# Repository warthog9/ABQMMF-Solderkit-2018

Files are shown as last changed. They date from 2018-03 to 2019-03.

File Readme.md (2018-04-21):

# 2018 Albuquerque Mini-Maker Faire Soldering Kit

This is the 2018 Albuquerque Mini-Maker Faire soldering kit, it's intended
to be a useful item that people will actually use as opposed to just a
series of blinky LEDs.  It makes use of the NodeMCU, which is based on the
ESP8266, a microcontroller that has wifi capabilities.

## Out of the box
Out of the box the kit will include the following things:
* PCB of the Cloud Sun variety (pictured below)
* 2x 15-pin, female, 0.1" headers
* 2x 4-pin, female, 0.1" headers
* 1x 1K Ohm resistor
* 1x 5mm Red LED
* 1x Diode
* 1x 3-AAA battery pack
* 1x Red button (intended to go in the middle - but doesn't matter)
* 4x Black buttons (electrically identical to the red)
* 1x 2x10-pin, male, 0.1" header
* 1x I2C, 4-pin, OLED screen
* 1x BME280, I2C 4-pin, breakout board
* 1x NodeMCU v2 (CP2102 USB chip type)

The board will boot up, once soldered up, and will show the following information on the OLED screen:
* Battery level (upper right corner)
* Temperature
* Barometric pressure
* Relative humidity

The buttons do the following:
* Top: Increases OLED screen brightness
* Bottom: Decreases OLED screen brightness
* Middle: Toggles temperature readout between Celsius and Fahrenheit (Default Fahrenheit)
* Left: Toggles between condensed or extended text on the OLED screen
* Right: Will toggle the two extra LEDs on the ESP12e/f module and the NodeMCU itself

The NodeMCU has been pre-loaded with [MicroPython](https://micropython.org), which is a slimmed down version of Python 3 intended for micro-controllers.  This is greater for people to start with, and you can find some basic tutorials on how to interact with the board quickly here:

* https://docs.micropython.org/en/latest/esp8266/esp8266/tutorial/intro.html
* https://github.com/unreproducible/tinysnakes

Wifi is disabled for this demo via [boot.py](https://github.com/warthog9/ABQMMF-Solderkit-2018/blob/master/src/boot.py), but can be easily changed and/or re-enabled.

Files were uploaded to the board using [ampy](https://github.com/adafruit/ampy)

## Schematic

Full schematic is here: [Schematic PDF](abqmmf2018-schematic.pdf)

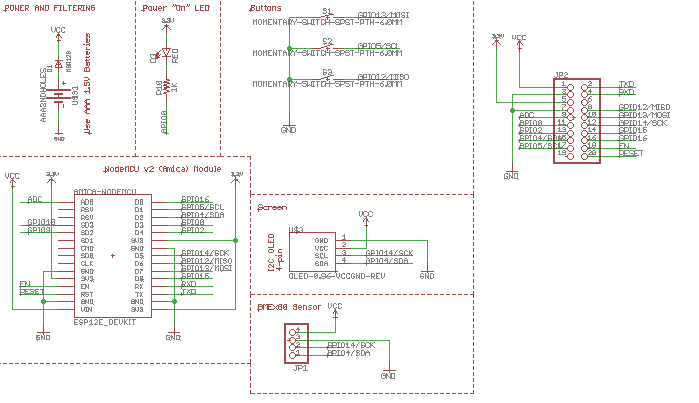
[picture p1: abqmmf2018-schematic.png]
Schematic image


### PCB outline
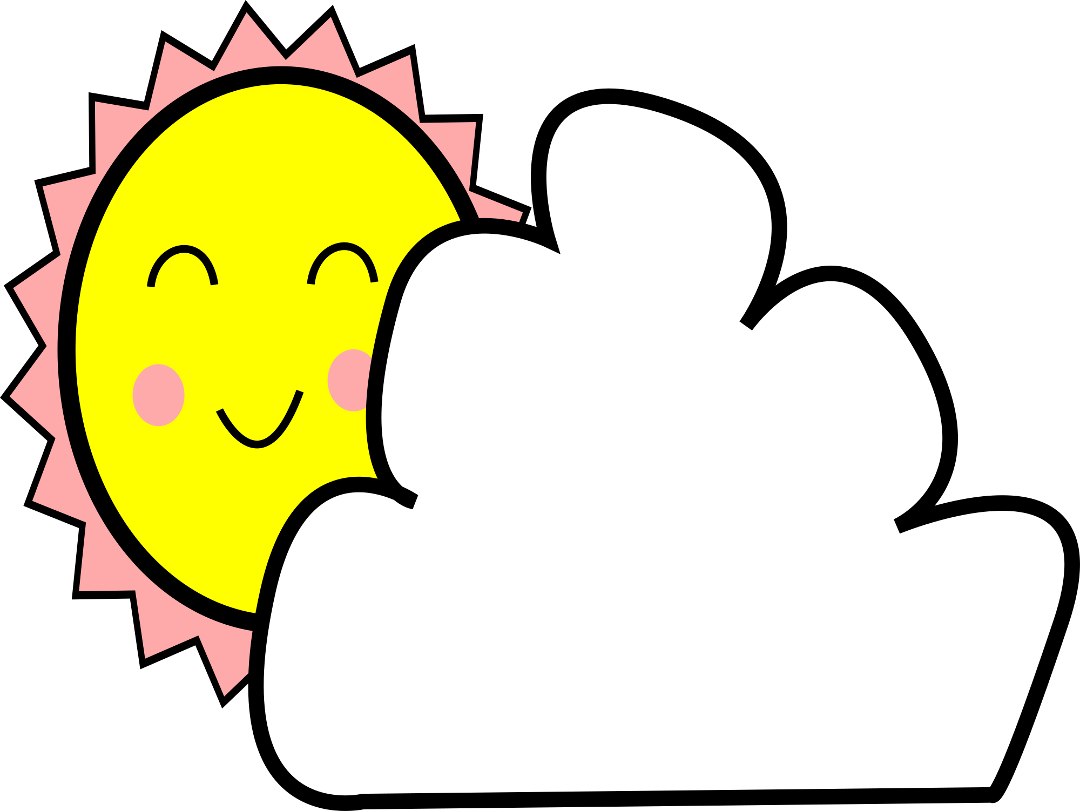
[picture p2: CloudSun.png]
Silkscreen and PCB Outline


### Prototype built up
Prototype board mostly built up

### Raw PCBs (prototypes)
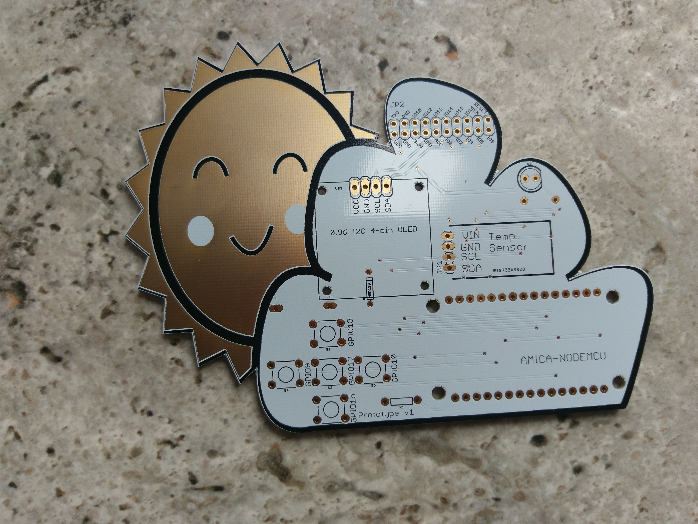
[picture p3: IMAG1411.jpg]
Bare prototype board - top

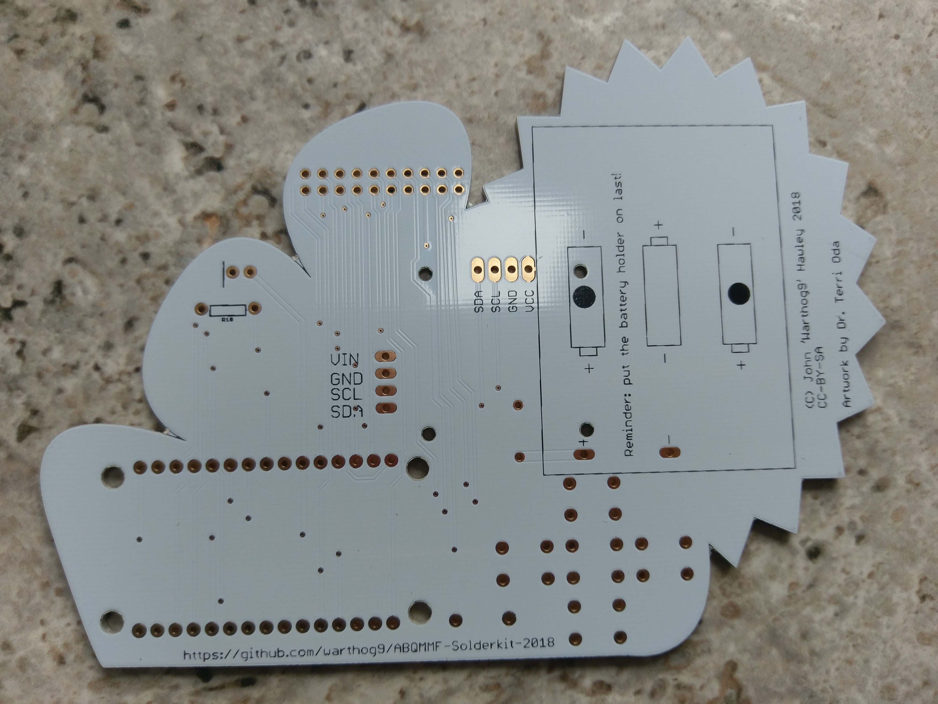
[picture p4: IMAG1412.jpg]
Bare prototype board - bottom


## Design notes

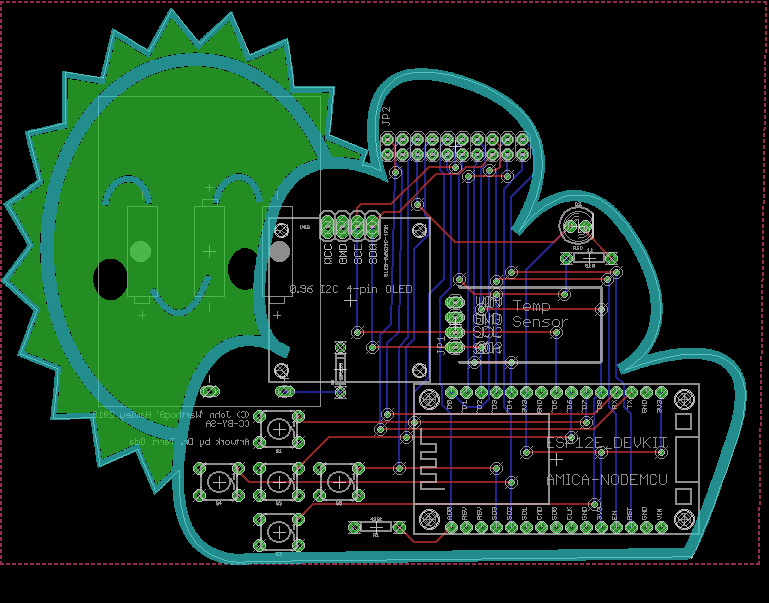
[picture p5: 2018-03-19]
CloudSun Board.png

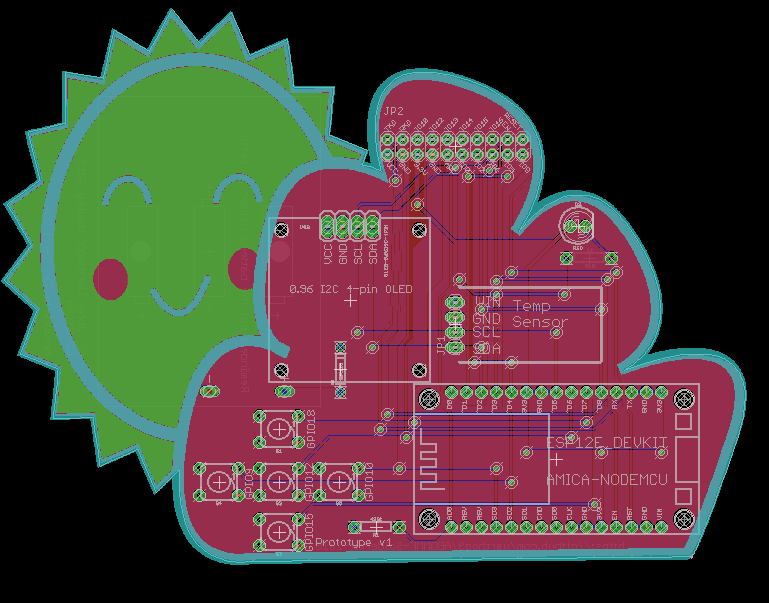
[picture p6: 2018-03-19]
CloudSun Board2.png

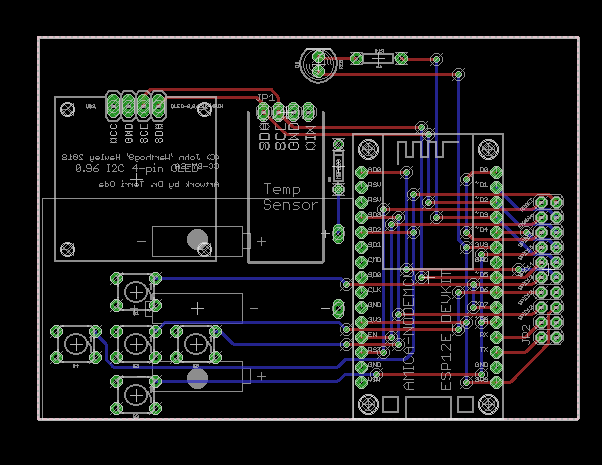
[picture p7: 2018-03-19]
board.png

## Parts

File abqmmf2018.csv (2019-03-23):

Part | Value | Device | Package | Description | PROD_ID | SF_SKU | VALUE
AMICA-NODEMCU | ESP12E_DEVKIT | ESP12E_DEVKIT | ESP12E_DEVKIT | ESP12E DEVKIT BOARD
D1 | MBR120 | DIODEDO-1N4148 | DO-1N4148 | Diode
D3 | RED | LED5MM | LED_5MM | LED (Generic)
JP1 |  | PINHD-1X4 | 1X04 | PIN HEADER
JP2 |  | PINHD-2X10 | 2X10 | PIN HEADER
R1 | 420k | 1KOHM-HORIZ-1/4W-1% | AXIAL-0.3 | 1kO resistor | RES-12182 |  | 1k
R10 | 1k | 1KOHM-HORIZ-1/4W-1% | AXIAL-0.3 | 1kO resistor | RES-12182 |  | 1k
S1 | MOMENTARY-SWITCH-SPST-PTH-6.0MM | MOMENTARY-SWITCH-SPST-PTH-6.0MM | TACTILE_SWITCH_PTH_6.0MM | Momentary Switch (Pushbutton) - SPST | SWCH-08441 | COM-00097
S2 | MOMENTARY-SWITCH-SPST-PTH-6.0MM | MOMENTARY-SWITCH-SPST-PTH-6.0MM | TACTILE_SWITCH_PTH_6.0MM | Momentary Switch (Pushbutton) - SPST | SWCH-08441 | COM-00097
S3 | MOMENTARY-SWITCH-SPST-PTH-6.0MM | MOMENTARY-SWITCH-SPST-PTH-6.0MM | TACTILE_SWITCH_PTH_6.0MM | Momentary Switch (Pushbutton) - SPST | SWCH-08441 | COM-00097
U$3 | OLED-0.96I2C-4PIN | OLED-0.96I2C-4PIN | OLED-I2C-4PIN | Common 0.96 OLED screen assembly
U$31 | AAA3NOHOLES | AAA3NOHOLES | AAA3-NOHOLES

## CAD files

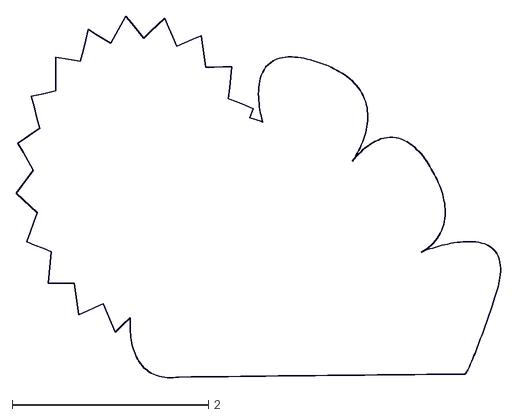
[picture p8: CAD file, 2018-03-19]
CloudSun-outline.dxf
4.94 x 3.69

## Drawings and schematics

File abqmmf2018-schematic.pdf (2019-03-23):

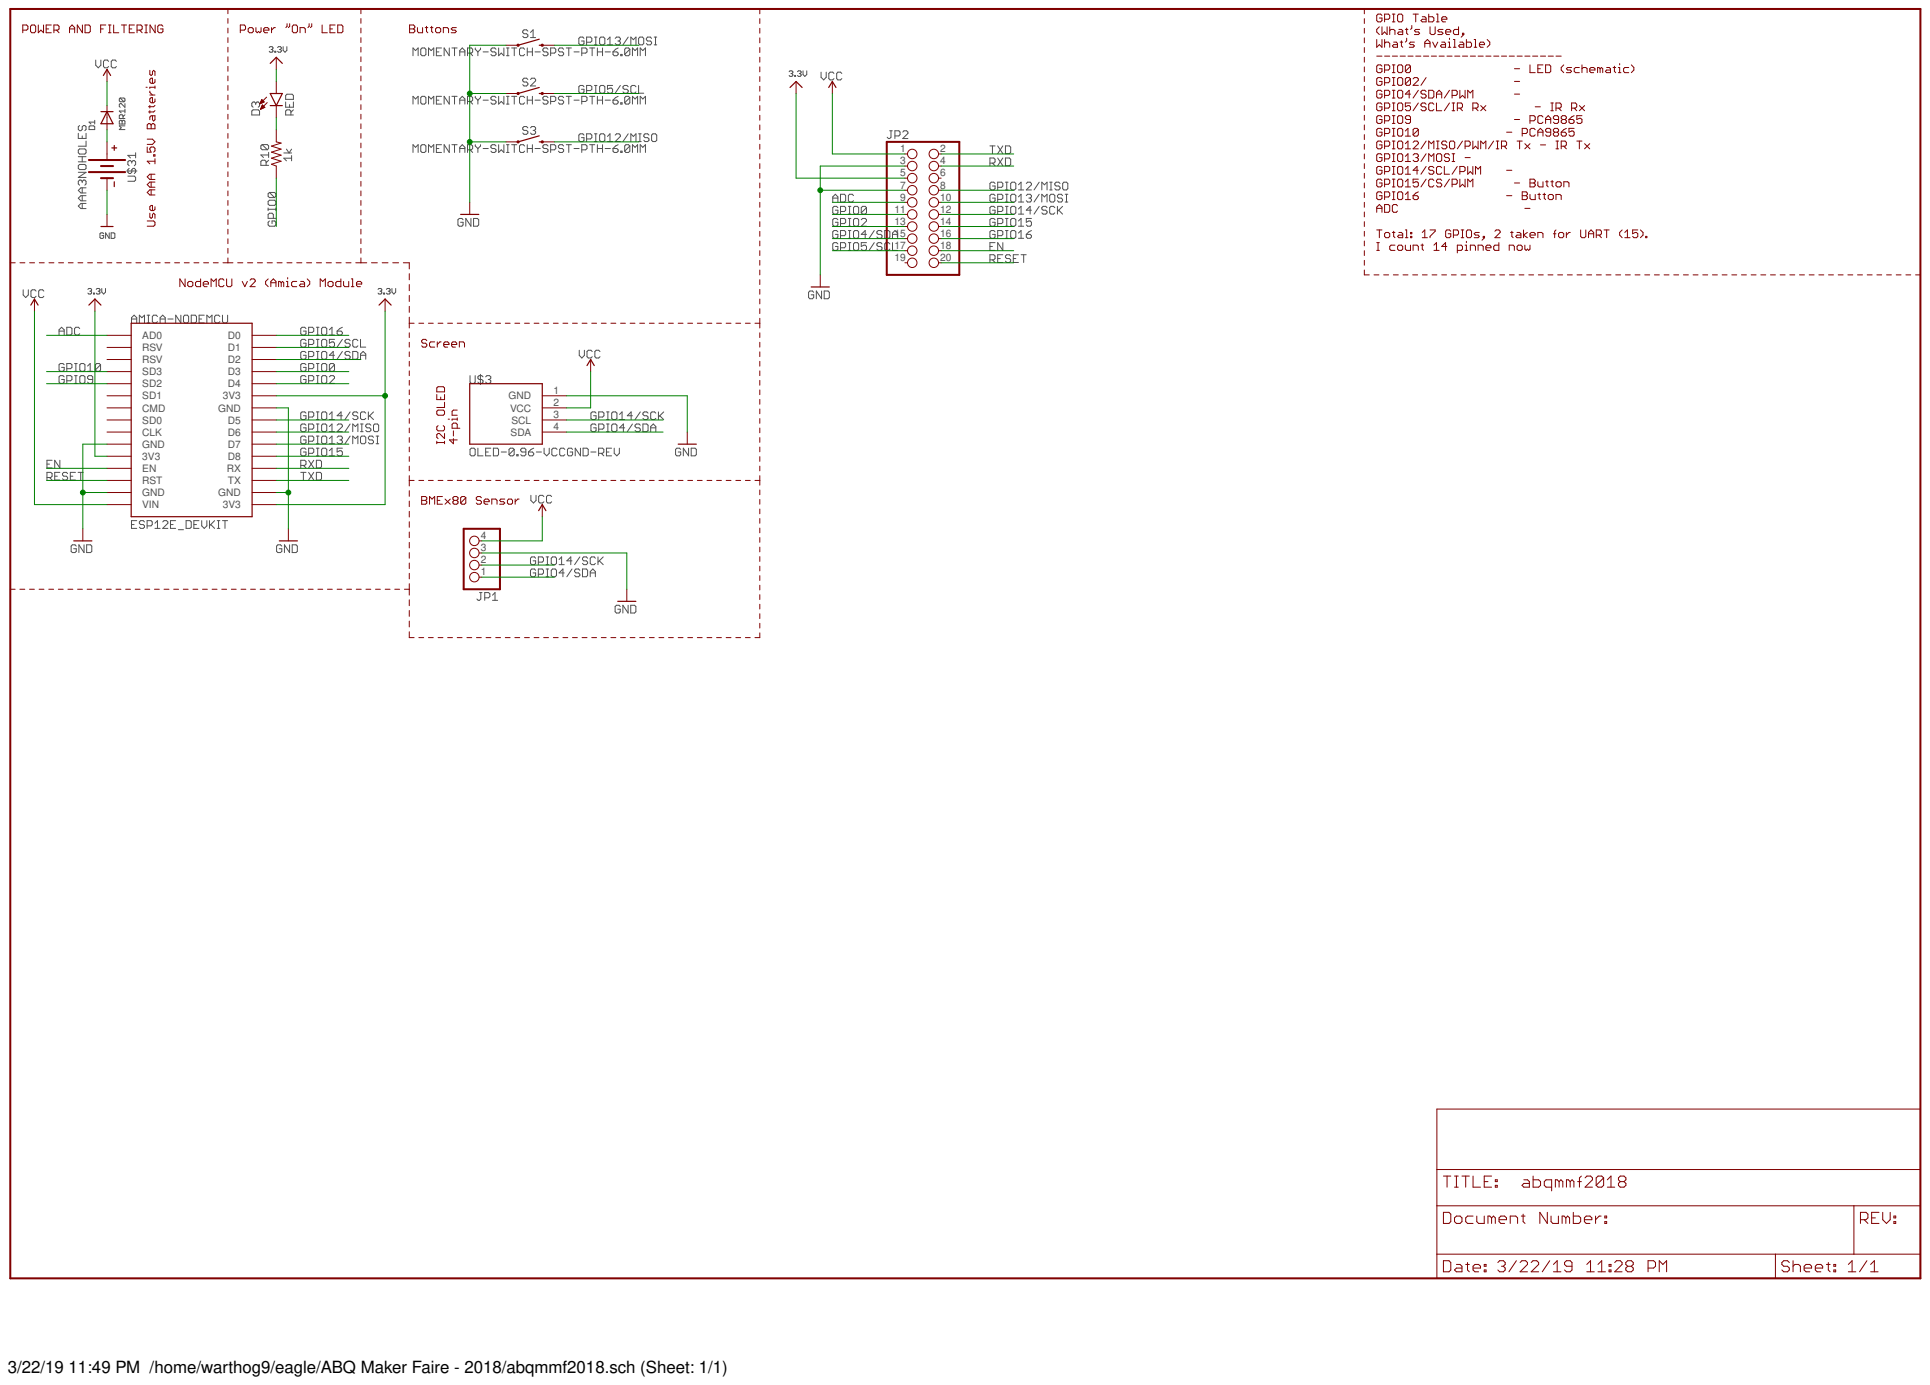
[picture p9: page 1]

3/22/19 11:49 PM /home/warthog9/eagle/ABQ Maker Faire - 2018/abqmmf2018.sch (Sheet: 1/1)

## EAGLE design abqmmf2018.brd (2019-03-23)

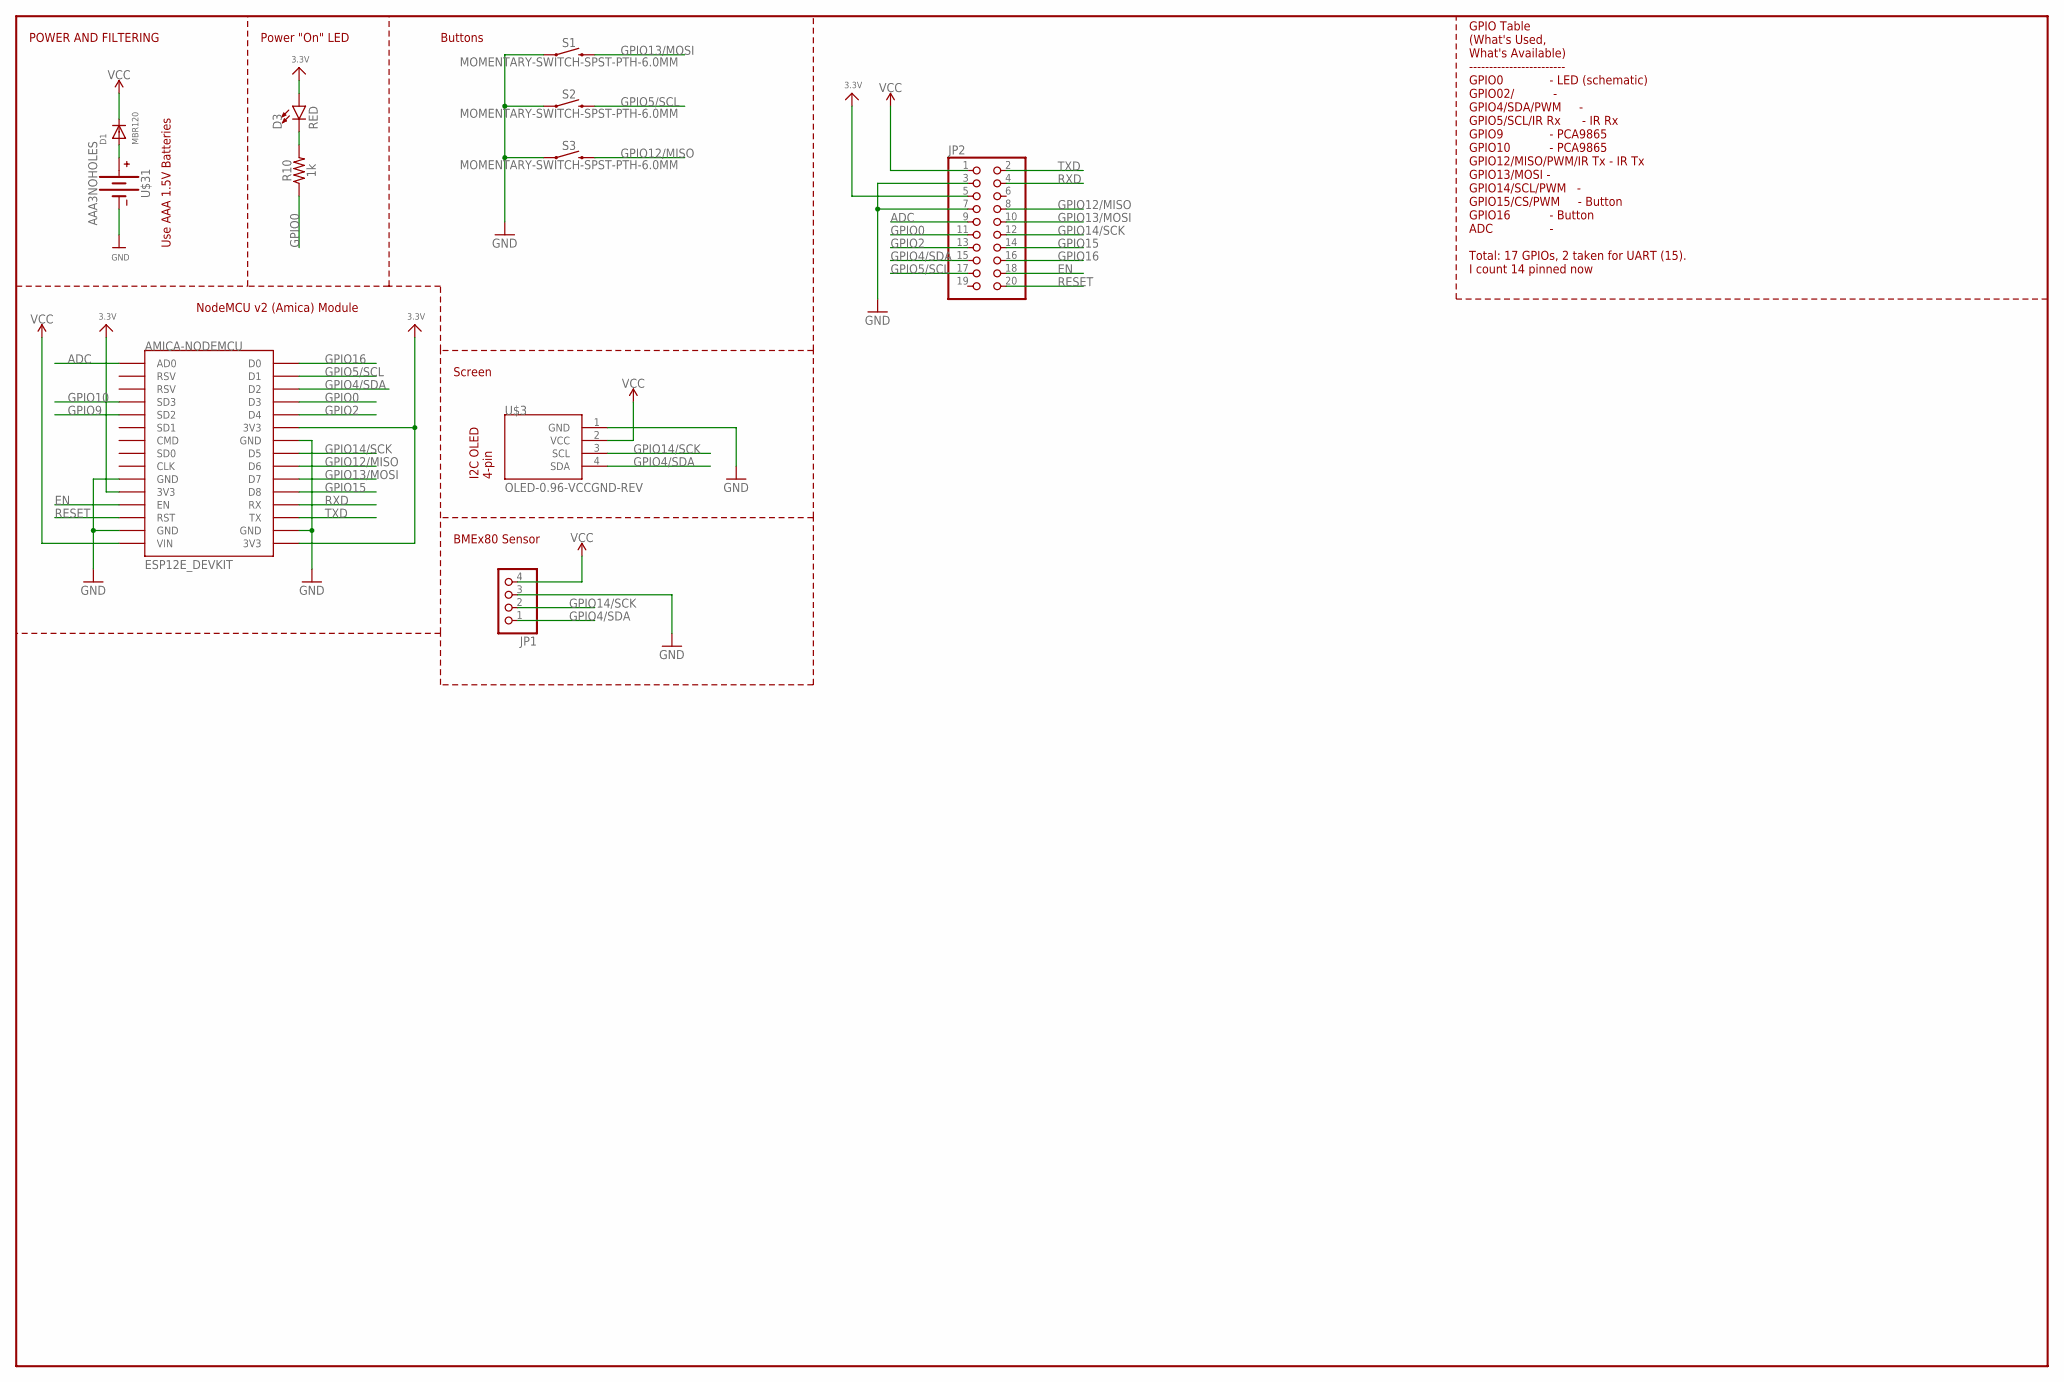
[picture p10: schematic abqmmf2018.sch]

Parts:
AMICA-NODEMCU: ESP12E_DEVKIT
D1: MBR120; DO-1N4148
D3: RED; LED_5MM
JP1: PINHD-1X4; 1X04
JP2: PINHD-2X10; 2X10
R10: 1k; AXIAL-0.3
S1, S2, S3: MOMENTARY-SWITCH-SPST-PTH-6.0MM; TACTILE_SWITCH_PTH_6.0MM
U$3: OLED-0.96-VCCGND-REV; OLED-I2C-4PIN-VCCGND-REV
U$31: AAA3NOHOLES; AAA3-NOHOLES

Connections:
3.3V: AMICA-NODEMCU.3V3@0 (3V3), AMICA-NODEMCU.3V3@1 (3V3), AMICA-NODEMCU.3V3@2 (3V3), D3.A, JP2.5
ADC: AMICA-NODEMCU.AD0, JP2.9
EN: AMICA-NODEMCU.EN, JP2.18
GND: AMICA-NODEMCU.GND@0 (GND), AMICA-NODEMCU.GND@1 (GND), AMICA-NODEMCU.GND@2 (GND), AMICA-NODEMCU.GND@3 (GND), JP1.3, JP2.3, JP2.7, S1.1, S2.1, S3.1, U$3.1 (GND), U$31.NEG (-)
GPIO0: AMICA-NODEMCU.D3, JP2.11, R10.P$1 (1)
GPIO2: AMICA-NODEMCU.D4, JP2.13
GPIO4/SDA: AMICA-NODEMCU.D2, JP1.1, JP2.15, U$3.4 (SDA)
GPIO5/SCL: AMICA-NODEMCU.D1, JP2.17, S2.3 (2)
GPIO9: AMICA-NODEMCU.SD2
GPIO10: AMICA-NODEMCU.SD3
GPIO12/MISO: AMICA-NODEMCU.D6, JP2.8, S3.3 (2)
GPIO13/MOSI: AMICA-NODEMCU.D7, JP2.10, S1.3 (2)
GPIO14/SCK: AMICA-NODEMCU.D5, JP1.2, JP2.12, U$3.3 (SCL)
GPIO15: AMICA-NODEMCU.D8, JP2.14
GPIO16: AMICA-NODEMCU.D0, JP2.16
unnamed: D1.A, U$31.POS (+)
unnamed: D3.K (C), R10.P$2 (2)
RESET: AMICA-NODEMCU.RST, JP2.20
RXD: AMICA-NODEMCU.RX, JP2.4
TXD: AMICA-NODEMCU.TX, JP2.2
VCC: AMICA-NODEMCU.VIN, D1.C, JP1.4, JP2.1, U$3.2 (VCC)

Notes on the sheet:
POWER AND FILTERING
Power "On" LED
NodeMCU v2 (Amica) Module
GPIO Table (What's Used, What's Available) ------------------------ GPIO0 - LED (schematic) GPIO02/ - GPIO4/SDA/PWM - GPIO5/SCL/IR Rx - IR Rx GPIO9 - PCA9865 GPIO10 - PCA9865 GPIO12/MISO/PWM/IR Tx - IR Tx GPIO13/MOSI - GPIO14/SCL/PWM - GPIO15/CS/PWM - Button GPIO16 - Button ADC - Total: 17 GPIOs, 2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
Buttons
Use AAA 1.5V Batteries
Screen
BMEx80 Sensor

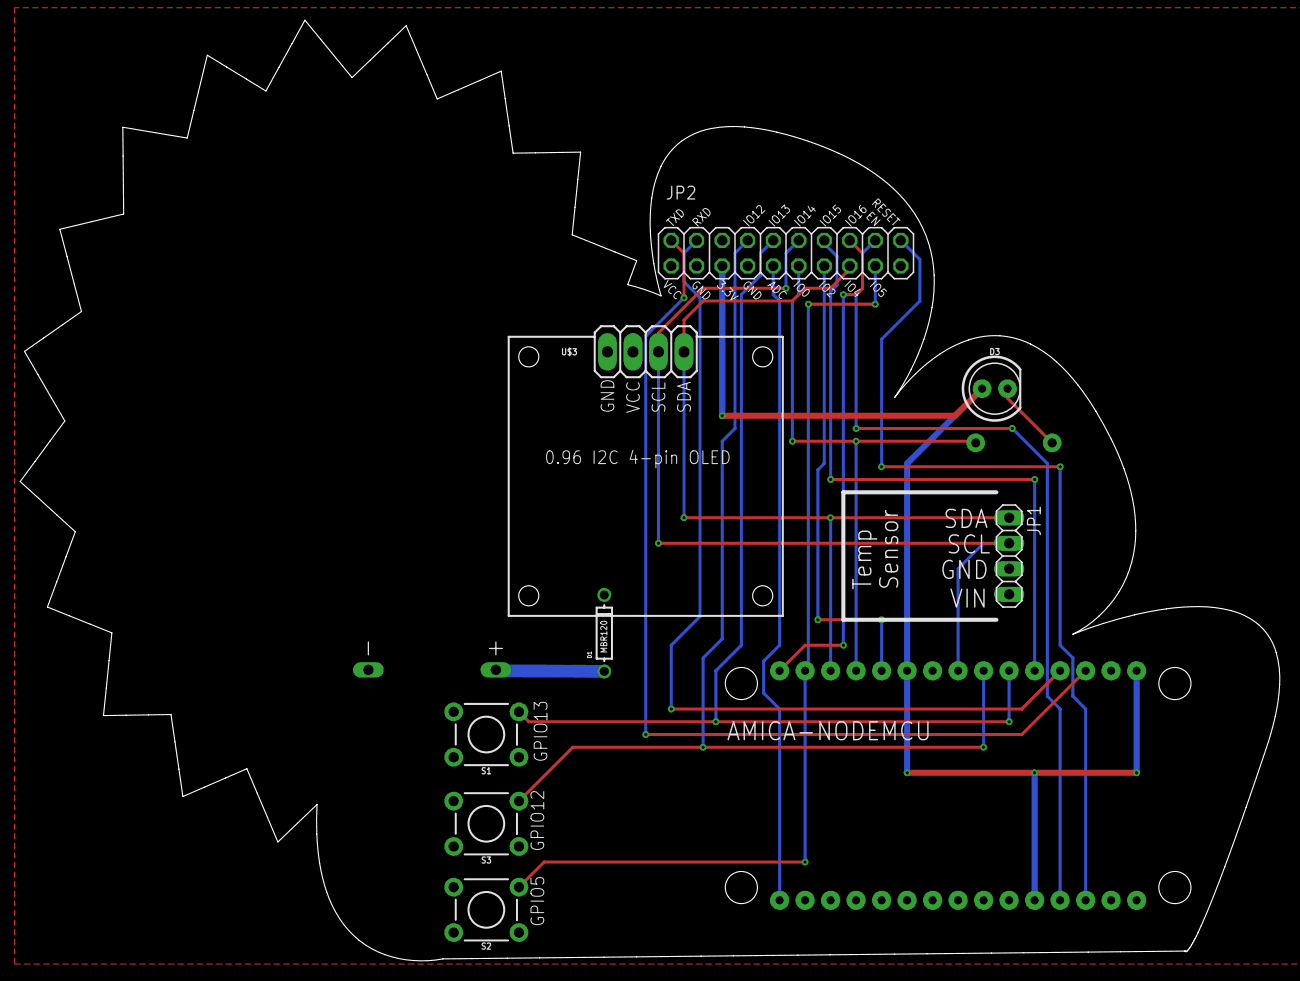
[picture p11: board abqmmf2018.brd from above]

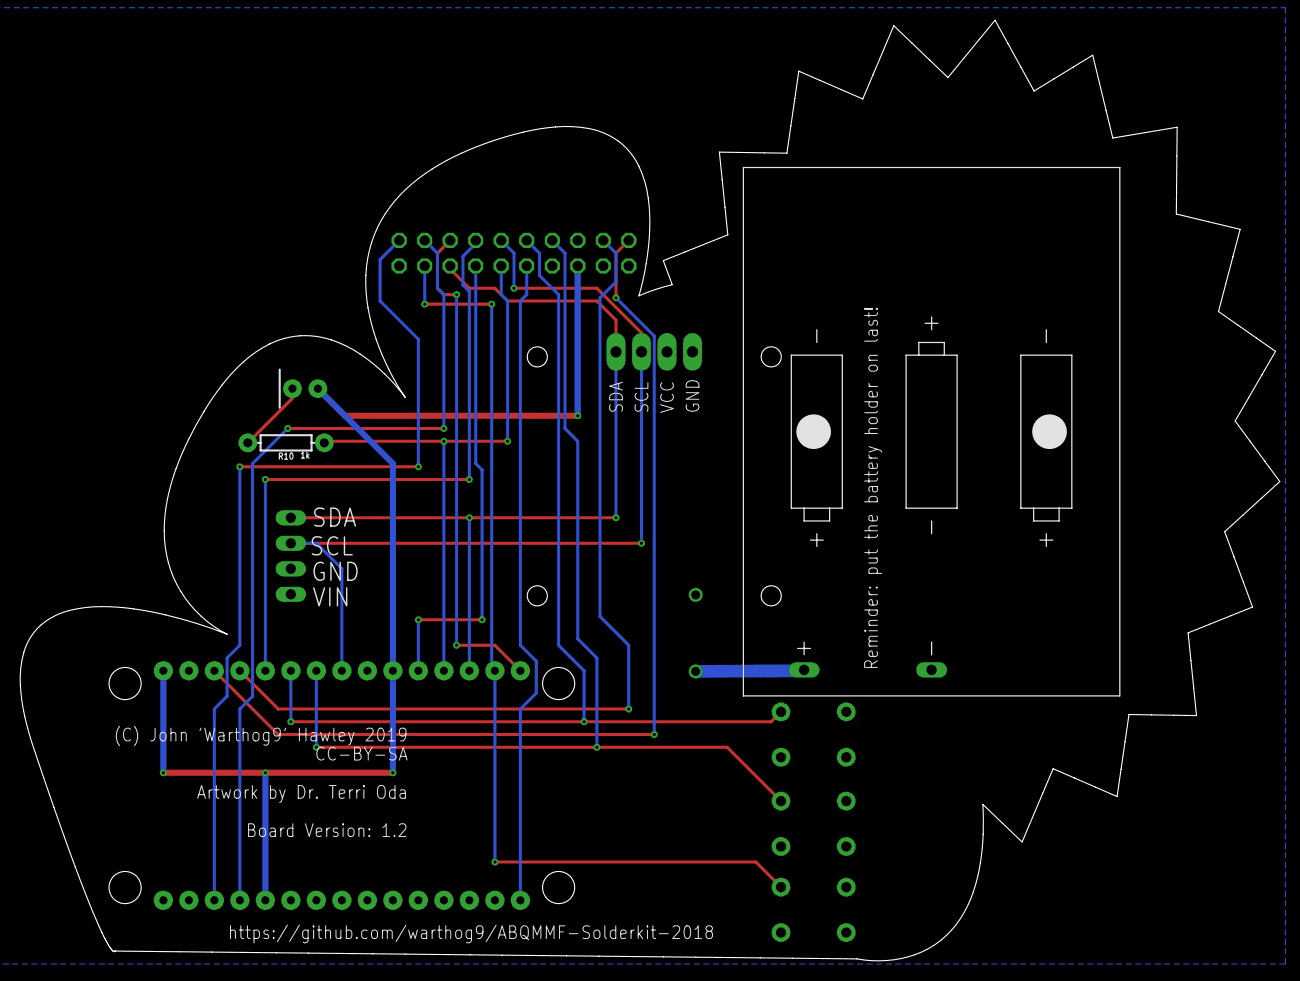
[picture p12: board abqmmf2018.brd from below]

Board: 2 copper layers, 125.5 x 93.7 mm, 11 parts (2 on the bottom side), 19 nets.

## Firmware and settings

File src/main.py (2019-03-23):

import machine
from machine import Pin, Signal, Timer
import bme280
import ssd1306

import time
import math

#import sys

# btree seems to be broken
# as it seems to stomp all over the
# fat filesystem internally
# after being modified quickly
## import btree

#
# These are needed for switching the 
# VCC read pin to the internal 
# - it's complicated
# 

import esp
from flashbdev import bdev

# End imports for vcc read flipping

pin_scl=14
pin_sda=4

pin_led_board=0

pin_led_node=16
pin_led_esp12=2

button_pin_up=13
button_pin_down=5
button_pin_middle=12


_pin_led_board = Pin(pin_led_board, machine.Pin.OUT)
_pin_led_node  = Pin(pin_led_node, machine.Pin.OUT)
_pin_led_esp12 = Pin(pin_led_esp12, machine.Pin.OUT)

led_board = Signal(_pin_led_board, invert=True)
led_node  = Signal(_pin_led_node, invert=True)
led_esp12 = Signal(_pin_led_esp12, invert=True)

leds = [ led_board, led_node, led_esp12 ]

pin_button_up     = machine.Pin( button_pin_up,     machine.Pin.IN, machine.Pin.PULL_UP )
pin_button_down   = machine.Pin( button_pin_down,   machine.Pin.IN, machine.Pin.PULL_UP )
pin_button_middle = machine.Pin( button_pin_middle, machine.Pin.IN, machine.Pin.PULL_UP )

buttons = [ pin_button_up, pin_button_down, pin_button_middle ]

#####################
# Real Code goes after here
#####################

#####################
# VCC flipping information
#####################
ADC_MODE_VCC = 255
ADC_MODE_ADC = 0

SCREEN_BRIGHTNESS = 100

def set_adc_mode(mode):
    sector_size = bdev.SEC_SIZE
    flash_size = esp.flash_size() # device dependent
    init_sector = int(flash_size / sector_size - 4)
    data = bytearray(esp.flash_read(init_sector * sector_size, sector_size))
    if data[107] == mode:
        return  # flash is already correct; nothing to do
    else:
        print( "*** Going to adjust the ADC type in the flashed memory" );
        print( "*** You will need to hit the 'RST' button, near the USB port" );
        print( "*** when it's done" );
        data[107] = mode  # re-write flash
        esp.flash_erase(init_sector)
        esp.flash_write(init_sector * sector_size, data)
        print("*** ADC mode changed in flash; restart to use it!")
        return

set_adc_mode( ADC_MODE_VCC )

#####################
# End of VCC Flipping code
#####################

#####################
# Instantiate the rest of the things we'll need
#####################

# This sets up what pins on the system are going
# to be I2C.  MicroPython does a 'soft' I2C for
# any pins (I.E. it's bit banging the I2C via gpio)
# and we need to tell MicroPython which pins to do this on
print( "Initialize the I2C pins...", end="")
##try:
i2c = machine.I2C(scl=machine.Pin(pin_scl), sda=machine.Pin(pin_sda) )
##except:
##    print( " FAILED")
##    print( "This is a fatal error - something is very wonky")
##    sys.exit()
print( " Success")

# this sets up the temp/humidity/pressure sensor
print( "Initialize the BME280 using I2C...", end="")
##try:
bme = bme280.BME280(i2c=i2c)
##except:
##    print( " FAILED")
##    print( "This is a fatal error - something is very wonky")
##    sys.exit()
print( " Success")

# this sets up the oled screen
print( "Initialize the OLED screen using I2C...", end="")
##try:
oled = ssd1306.SSD1306_I2C( 128, 32, i2c)
##except:
##    print( " FAILED")
##    print( "This is a fatal error - something is very wonky")
##    sys.exit()
print( " Success")


# This setups the reading of the VCC state
# this boils down to the voltage on the system
# which can be equated to how much battery is
# left
print( "Initialize the ADC as VCC...", end="")
##try:
vcc_stat = machine.ADC(1)
##except:
##    print( " FAILED")
##    print( "This is a fatal error - something is very wonky")
##    sys.exit()
print( " Success")


#####################
# End instantiation
#####################

#####################
# Lets run through some basic diagnostics quick, clearing the screen, blinking some LEDs, etc
#####################

# First turn off the LEDs, and clear the screen
print( "Turning off all the LEDs...", end='')
for led in leds:
    print(".", end='')
    led.off()
print( "!" )

print( "Clearing the OLED screen...", end='')
oled.fill(0)
oled.show()
print( " Success")

# Ok lets put something on the LEDs, show some 'life'
for led in leds:
    print( "Toggling LED:")
    for x in range( 0, 3 ):
        if( not led.value() ):
            print( "        On")
            led.on()
        else:
            print( "        Off")
            led.off()
        time.sleep( 0.5 )
    print( "        Final - Off")
    led.off()


#####################
# End Startup testing code
#####################


#####################
# Lets just setup the LED that's on the board as a PWM, we may 'breath' it later
#####################
breath_i = 0

def breath( x ):
    global pwmLed
    global breath_i

    breath_i = breath_i + 1

    #newduty = int(math.sin(breath_i / 10 * math.pi) * 500 + 500)
    #newduty = int(math.sin(breath_i / 200 * math.pi) * 375 + 375)
    #newduty = int( (math.sin(breath_i * math.pi * 1.5) / 2) * 250 + 250 )
    newduty = 1024 - int( (math.exp(math.sin(breath_i/20.0 * math.pi)) - 0.36787944) * 108.0 );

    if( newduty >= 1010 ):
        return

    pwmLed.duty( newduty )
    ##print( "breath_i:", end='')
    ##print( str(breath_i) )
    ##print( "Duty:", end='')
    ##print( str(newduty) )

print( "Initialize the Board LED as a PWM...", end="")
##try:
pwmLed = machine.PWM(_pin_led_board)
pwmLed.freq(1000)
pwmLed.duty(1024)

breathTimer = Timer(-1)
breathTimer.init(period=100, mode=Timer.PERIODIC, callback=breath)
##except:
##    print( " FAILED")
##    print( "This is a fatal error - something is very wonky")
##    sys.exit()
print( " Success")

#####################
# Read in config data
#####################

##database_filename = "config.db"

### open the database:
##try:
##    f = open(database_filename, "r+b")
##except OSError:
##    f = open(database_filename, "w+b")
##
##db = btree.open(f)
##
###defaults
##if( not db.get("brightness") ):
##    db[b"brightness"]= b"100"
##    #db.flush()
##
##if( not db.get("temp_mode") ):
##    db[b"temp_mode"] = b"F"
##    #db.flush()

#
# Classes, mostly for ISR, go here
#

#
# Function definitions
#

def draw_battery():
    max_bat = 3300 #3.3V * 1000
    bat_dead = 1200 # about 1.2V
    # note we have 14 steps in this battery meter
    # 16 pixels wide, 2 pixels for the edges = 14
    bat_steps = 13
    
    bat_lost = max_bat - vcc_stat.read()

    bat_per_lost = round(bat_lost / ((max_bat - bat_dead) / bat_steps))

    oled.fill_rect(112,0,16,6,1)
    oled.fill_rect(110,2,3,2,1)
    oled.fill_rect(113,1,bat_per_lost,4,0)


def set_contrast( x ):
    global SCREEN_BRIGHTNESS

    oled.contrast( x )
    SCREEN_BRIGHTNESS = x


##    brightness = db[b"brightness"]
##    db[b"brightness"] = bytes(str(x), "ascii")
    
def cb_adjustBrightnessUp( pin ):
##    bright = int(db[b"brightness"])
    bright = SCREEN_BRIGHTNESS

    if(
        bright >= 255
    ):
        return

    bright = bright + 25

    if( bright >= 255 ):
        bright = 255

    set_contrast( bright )
    #print( "cb_adjustBrightnessUp "+ str( bright ) +"|"+ str( SCREEN_BRIGHTNESS ) )

def cb_adjustBrightnessDown( pin ):
##    bright = int(db[b"brightness"])
    bright = SCREEN_BRIGHTNESS

    if(
        bright <= 0
    ):
        return

    bright = bright - 25

    if( bright <= 0 ):
        bright = 0

    set_contrast( bright )

    #print( "cb_adjustBrightnessDown "+ str( bright ) +"|"+ str( SCREEN_BRIGHTNESS ) )

USE_F = 1

def cb_switchCF( pin ):
    global USE_F

    USE_F = not USE_F

    #if( USE_F ):
    #    USE_F = 0
    #else:
    #    USE_F = 1

USE_TXT = 0

def cb_switchText( pin ):
    global USE_TXT

    USE_TXT = not USE_TXT

    #if( USE_TXT ):
    #    USE_TXT = 0
    #else:
    #    USE_TXT = 1

def cb_LEDTOG( pin ):
    ##print( "LED TOG: "+ str(led_esp12.value()) +" | "+ str(led_esp12.value()) )
    if( not led_esp12.value() and not led_node.value() ):
        led_esp12.on()
        return

    if( led_esp12.value() and not led_node.value() ):
        led_node.on()
        return

    if( led_esp12.value() and led_node.value()):
        led_esp12.off()
        return

    if( not led_esp12.value() and led_node.value()):
        led_node.off()
        return


pin_button_up.irq( trigger=machine.Pin.IRQ_FALLING, handler=cb_adjustBrightnessUp)
pin_button_down.irq( trigger=machine.Pin.IRQ_FALLING, handler=cb_adjustBrightnessDown)
pin_button_middle.irq( trigger=machine.Pin.IRQ_FALLING, handler=cb_switchCF)

while( True ):
    bme_data = bme.read_compensated_data()
    tTemp = bme_data[0]
    del bme_data

    tPress = bme.values[1]
    tHum = bme.values[2]

    if vcc_stat.read() == 65535:
        # So vcc_stat.read() will read wonky data till
        # the system is rebooted and the ADC line is
        # switched to the 'right' way to read the battery
        #
        # where 'right' is defined as what we want
        # it to do, and without external resistors 
##        oled.text( "Please Press the", 0, 0, 100)
##        oled.text( "'RST' button", 0, 10, 100)
##        oled.text( "below usb", 0, 20, 100) 
##        oled.show()
        # break out of the loop entirely, this
        # will drop the board to a REPL prompt
        break

    fTemp = "{}F".format( 9.0/5.0 * (tTemp // 100) + 32)
    #cTemp = "{}C".format(tTemp / 100) 

    if( USE_F ):
        tTemp = fTemp
    else:
        #tTemp = cTemp
        tTemp = bme.values[0]

    if( USE_TXT ):
        exTemp = "emp"
        exPress = "ress"
        exHum = "um"
    else:
        exTemp = ""
        exPress = ""
        exHum = ""

    oled.fill(0)
    oled.text( 'T'+ exTemp +':'+ tTemp, 0, 0, 100)
    oled.text( 'P'+ exPress +':'+ str(tPress), 0, 10, 100)
    oled.text( 'H'+ exHum +':'+ str(tHum), 0, 20, 100)

    ##oled.text( "{0:.2f}".format(vcc_stat.read() / 1000) , 90, 20, 100)
    draw_battery()

    oled.show()

    ##db.flush()

    #print( "breath_i: ", end='')
    #print( str(breath_i) )
    #print( "PWM Duty:"+ str(pwmLed.duty()) ) 

    print( "To break hit <ctrl>+c then enter: breathTimer.deinit()" )
    time.sleep(1)

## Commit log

2018-03-19 Adding the 2018 prototype board files, this is a completed board
    [CloudSun-outline.dxf, abqmmf2018.brd, abqmmf2018.sch]
2018-03-19 Adding prototype gerbers
    [abqmmf2018.drills.xln]
2018-03-19 Adding additional Schematic pdf and board picture
2018-03-19 Adding gerbers zip file
2018-03-28 Moving Screen & Sensor, Remove ADC Resistor
    Moving the Sensor more right since it's smaller than I had
    somewhat expected, so that's nice. Moved the screen so that
    it's more inside the cloud.
    Obviously had to do some rerouting to accomodate. Like it a
    little better anyway.
    Also removed the ADC voltage divider resistor. Turns out
    you can muck with the boot firmware enough to flip the ADC
    line to measure a 3.3V VDD value. This seems to return about
    2.9V with a full battery, and will go until it hits about
    1.53V-ish before the NodeMCU just falls over. Amusingly the
    OLED screen (on my test) kept going.
    [abqmmf2018.brd, abqmmf2018.sch]
2018-04-21 BRD: Fixing Typo next to up button - GPIO13
    I had typoed on the GPIO# next to the Up button
    I had put 'GPIO18', should be 'GPIO13' - fixed.
    [abqmmf2018.brd]
2018-04-21 Button GPIO15 -> GPIO5
    GPIO15 is apparently always pulled low due
    to boot things (yay), so switching to GPIO5
    to work around it.
    [abqmmf2018.brd, abqmmf2018.sch]
2018-04-21 BRD: minor re-routing on gpio5 button
    [abqmmf2018.brd]
2018-04-21 BRD: cleaning up the DRCs
    This is all because of the PCBWay logo placement
    [abqmmf2018.brd]
2018-04-21 Adding the tDocu and bDocu to silkscreen layer
    The extra outline information for the Nodemcu
    is in the docu layers, figured it's easier to
    just add those to the cam then to re-do the part
    so that folks can see which way around it's supposed
    to go
2018-04-21 BRD: moving resistor value info to tPlace
    mainly so that this shows up on the silkscreen
    [abqmmf2018.brd]
2018-04-21 BRD: something got unrotated?
    [abqmmf2018.brd]
2018-04-21 Adding BOMs
    [abqmmf2018.csv, abqmmf2018.xlsx]
2018-04-21 Source Code: Initial commit, this is what is shipped on the 2018 kits
    This adds a git submodule for the bme280 so we can track that,
    a quick make file for the bme280.mpy (this is needed to keep ram
    usage down), and some extra git ignores.
    I'm throwing in the shell script I used to flash the boards, mostly
    as an example of how to flash the boards - not intending it to be a
    definitive example
2019-03-13 Remove accidental double reference
    S2, Pad 3 was accidentally assigned to both GPIO15 and GPIO5/SCL
    Removing GPIO15 since 5 is what's actually routed
    [abqmmf2018.brd]
2019-03-13 Removing Buttons for GPIO9/10
    These are basically unusable on a certain portion of NodeMCUs,
    so removing them entirely
    [abqmmf2018.brd, abqmmf2018.sch]
2019-03-13 Removing GPIO9/10 from expansion header
    These are unusable pins on enough NodeMCUs I'm going to go ahead
    and remove the pins in the general sense
    [abqmmf2018.brd, abqmmf2018.sch]
2019-03-13 Use the 0.96in OLED pinout that's got vcc/gnd reversed
    [abqmmf2018.brd, abqmmf2018.sch]
2019-03-23 Adjusting the Silkscren, bumping version to 1.2, (c) to 2019
    [abqmmf2018.brd]
2019-03-23 Fix Silkscreen for down button, to GPIO5 from GPIO15
    [abqmmf2018.brd]
2019-03-23 Cleaning up DRC issues
    [abqmmf2018.brd]
2019-03-23 Updating the Schematic to reflect the changes
2019-03-23 BOM changes to reflect the now missing 2 buttons
    [abqmmf2018.csv, abqmmf2018.xlsx]
2019-03-23 Removing the Left and Right buttons since they are no longer used
    [main.py]
2019-03-23 Move the gerbers.zip out of the zip directory
2019-03-23 Updating Gerbers
    [abqmmf2018.drills.xln]
2019-05-06 Fixing gerbers

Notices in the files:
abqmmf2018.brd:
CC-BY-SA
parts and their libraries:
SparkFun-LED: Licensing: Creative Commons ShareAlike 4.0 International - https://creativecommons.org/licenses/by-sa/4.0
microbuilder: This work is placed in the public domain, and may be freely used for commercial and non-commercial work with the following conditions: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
